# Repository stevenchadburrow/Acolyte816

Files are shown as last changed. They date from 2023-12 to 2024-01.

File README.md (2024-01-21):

# Acolyte816

An Acolyte Computer using the W65C816S.

It runs at 12.5 MHz and has 1 MB of RAM.  Video output of 64-colors at 320x240 or monochrome at 640x240.  PS/2 Keyboard and Mouse, 2x Genesis Controllers, and 1-Voice Square wave audio output.

This is a ROM-less design, having 512 bytes of bootloader code in the PIC16F886 "spoon feeding" the '816 on power-up or reset.  After that the PIC controls the MicroSD Card to access up to 2GB of memory.

The Simulator is powered by gianlucag's 6502 emulator library, with Agumander's W65C02 edits.  The LICENSE.txt pertains to the "mos6502-Edit816.h" and "mos6502-Edit816.cpp" files only.

BODGES REQUIRED:  The 74AHCT245 connected to the PIC needs two changes: One, Pin 1 is no longer R/W but instead connected to +5V. Two, Pin 19 is connected to RC5.  Also, the FTDI USB 6-pin connector has RTS and DTS lines cut and no longer connected to RC4 and RC5.

A picture of the board after bodges.
<kbd>
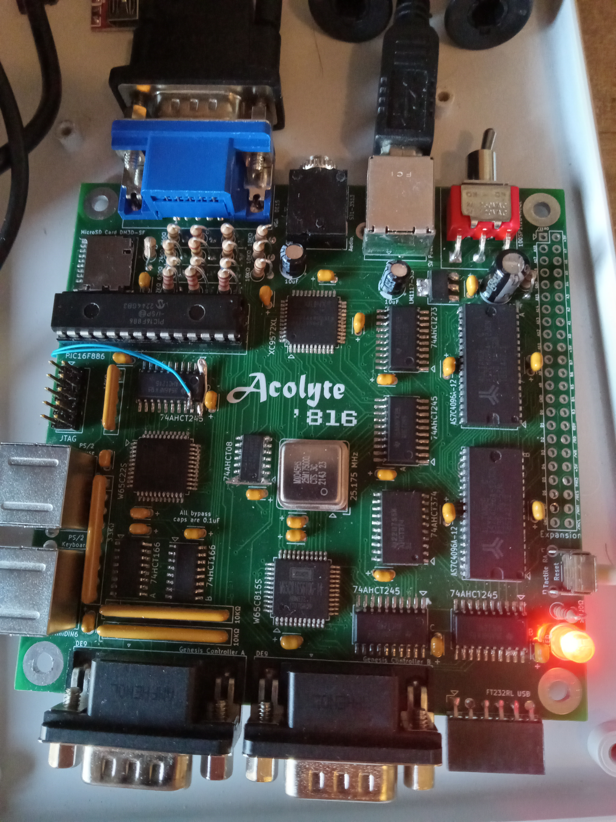
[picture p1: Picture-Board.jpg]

</kbd>

Splash showing 64-colors and text display together.
<kbd>
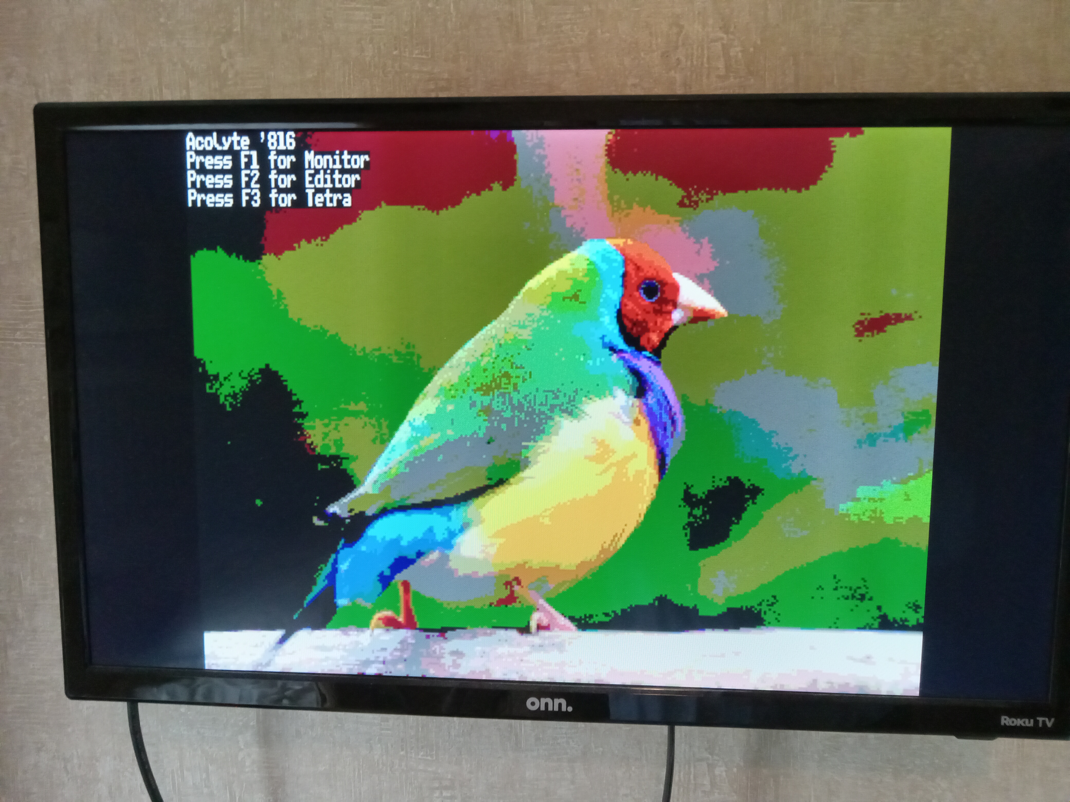
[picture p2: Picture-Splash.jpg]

</kbd>

Bootloader fallback monitor, when SDcard is not present.
<kbd>
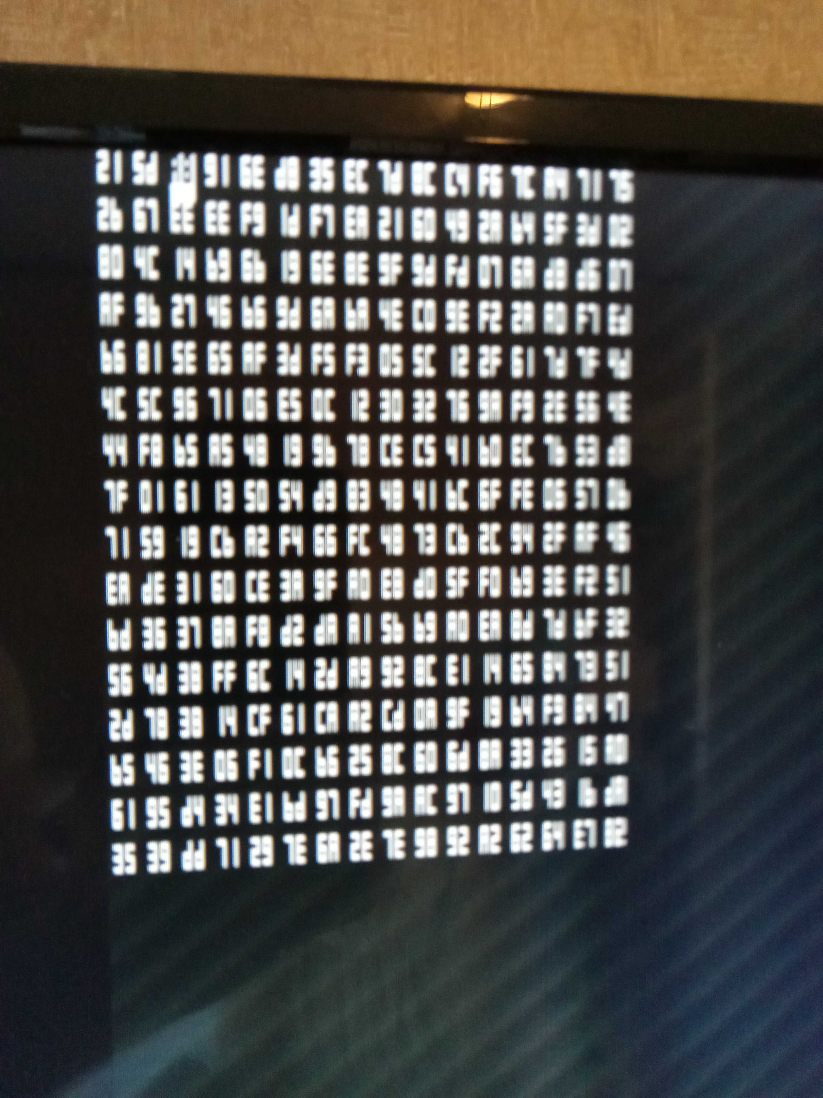
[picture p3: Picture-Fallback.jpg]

</kbd>

Basic system monitor for read/write/execute.
<kbd>
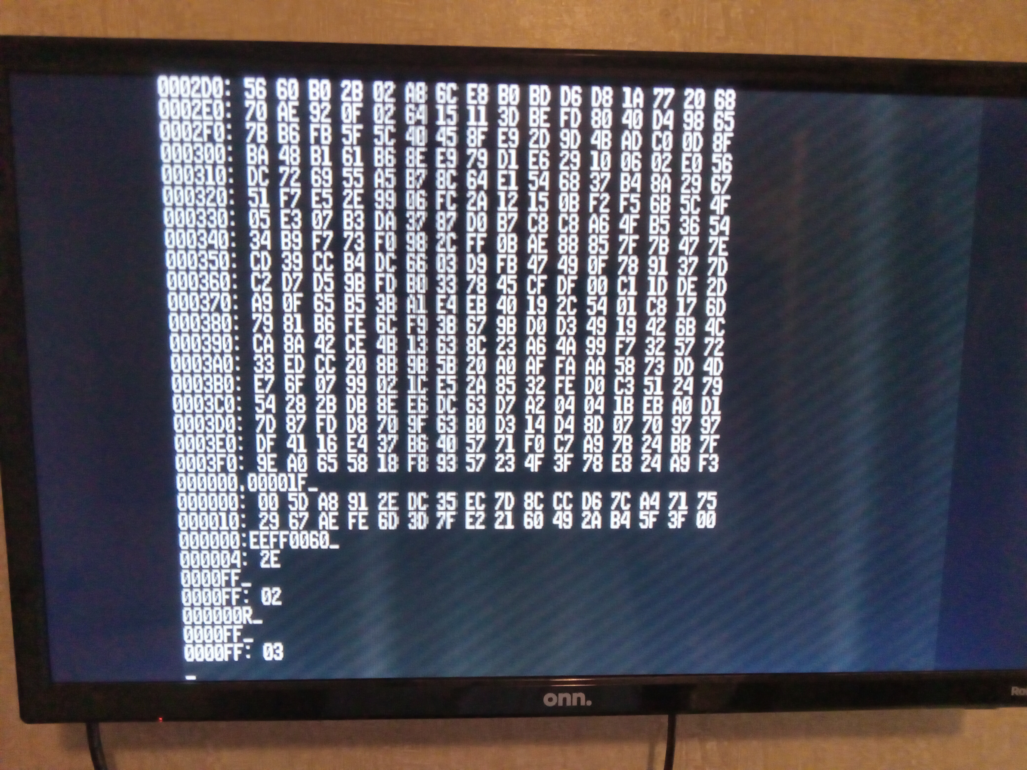
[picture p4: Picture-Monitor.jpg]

</kbd>

Text editor with vertical scrolling, will be used as IDE for a higher level language soon.
<kbd>
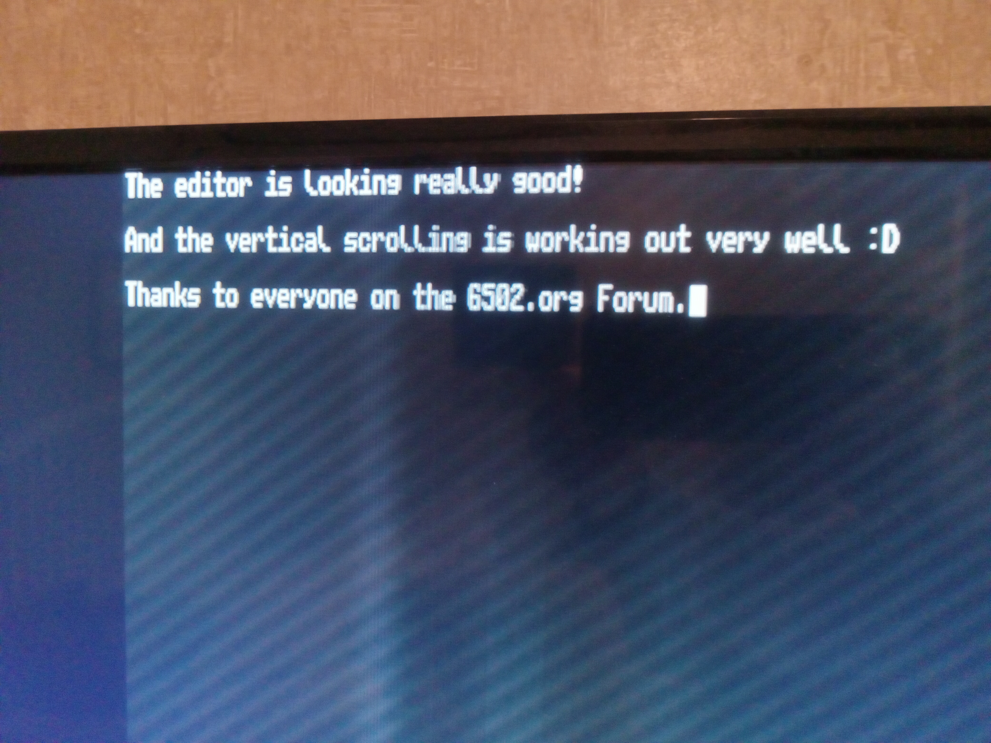
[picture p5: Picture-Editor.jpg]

</kbd>

First game for the system: Tetra!
<kbd>
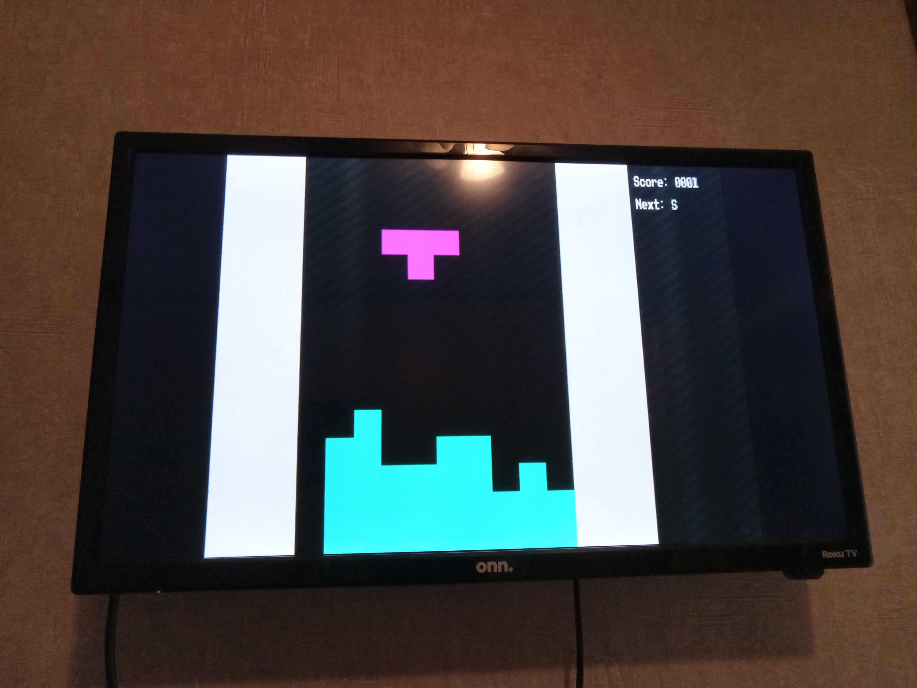
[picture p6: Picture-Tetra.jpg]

</kbd>

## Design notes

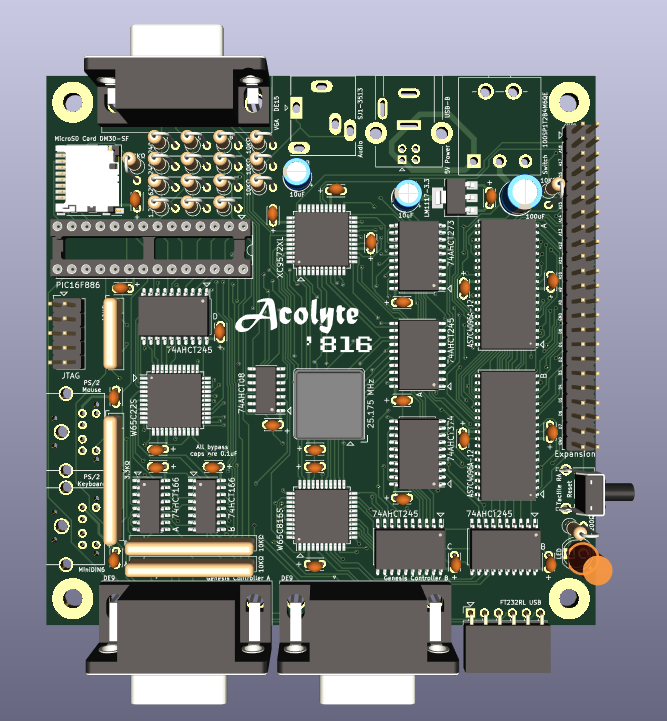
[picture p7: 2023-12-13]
Acolyte816-Routed.png

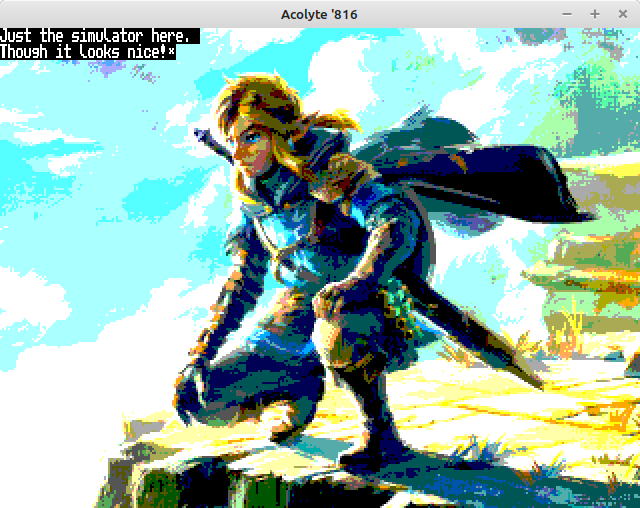
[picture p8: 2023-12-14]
Simulator-Demo.png

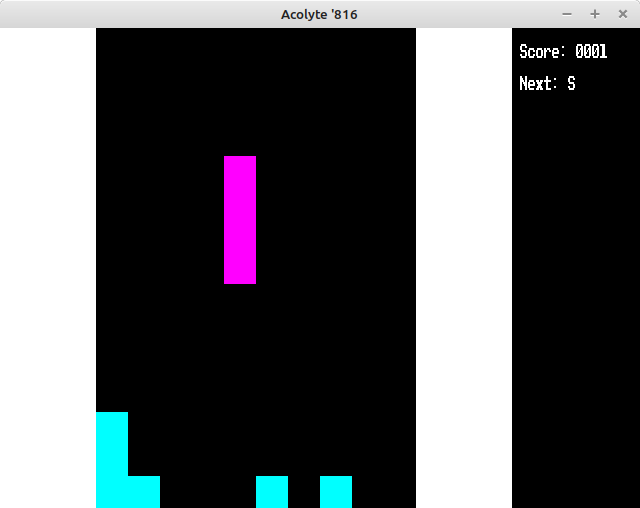
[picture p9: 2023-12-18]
Simulator-Tetra.png

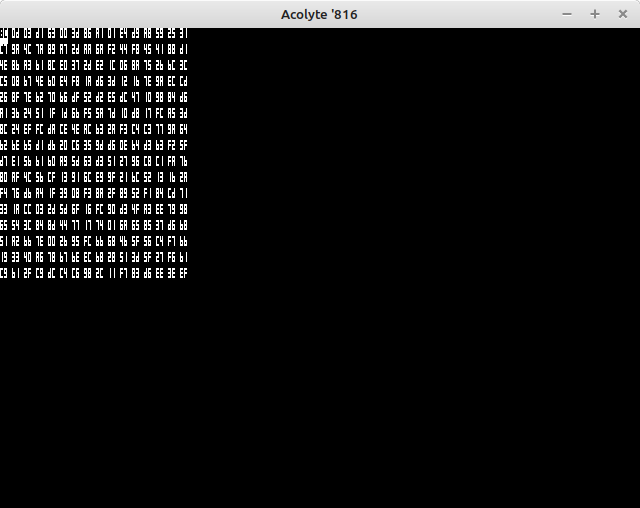
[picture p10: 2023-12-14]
Simulator-Bootloader.png

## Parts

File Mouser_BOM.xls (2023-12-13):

SHOPPING CART
This is not an invoice
13-Dec-23 14:43:57
 | Mouser # | Mfr. # | Manufacturer | Customer # | Description | RoHS | Lifecycle | Order Qty. | Price (USD) | Ext.: (USD)
1 | 913-AS7C4096A-12JCN | AS7C4096A-12JCN | Alliance Memory |  | SRAM SRAM, 4Mb, 512K x 8, 5V, 36pin SOJ, 12ns, Commercial Temp - Tube | RoHS Compliant |  | 2 | $5.77 | $11.54
2 | 955-W65C816S6TQG-14 | W65C816S6TQG-14 | Western Design Center (WDC) |  | Microprocessors - MPU 16-bit MPU 44 Pin QFP package | RoHS Compliant |  | 1 | $9.97 | $9.97
3 | 955-W65C22S6TQG-14 | W65C22S6TQG-14 | Western Design Center (WDC) |  | I/O Controller Interface IC Interface Adapter 44 Pin QFP package | RoHS Compliant |  | 1 | $9.66 | $9.66
4 | 579-PIC16F886-I/SP | PIC16F886-I/SP | Microchip |  | 8-bit Microcontrollers - MCU 14KB Flash 368 RAM 25 I/O | RoHS Compliant |  | 2 | $2.97 | $5.94
5 | 217-XC9572XL-7VQG44C | XC9572XL-7VQG44C | Xilinx |  | CPLD - Complex Programmable Logic Devices 3.3V 72-mc CPLD | RoHS Compliant |  | 1 | $13.50 | $13.50
6 | 595-SN74AHCT245PWR | SN74AHCT245PWR | Texas Instruments |  | Bus Transceivers Tri-State Octal Bus | RoHS Compliant |  | 4 | $0.46 | $1.84
7 | 595-SN74AHCT374PWR | SN74AHCT374PWR | Texas Instruments |  | Flip Flops Tri-State Octal | RoHS Compliant |  | 1 | $0.43 | $0.43
8 | 595-SN74AHCT273PWR | SN74AHCT273PWR | Texas Instruments |  | Flip Flops Octal w/ Clear | RoHS Compliant |  | 1 | $0.61 | $0.61
9 | 798-DM3D-SF | DM3D-SF | Hirose Electric |  | Memory Card Connectors MICRO SD CD CONN STD SMT PUSHPULL | RoHS Compliant |  | 1 | $1.82 | $1.82
10 | 649-61729-1011RLF | 61729-1011RLF | Amphenol |  | USB Connectors 4P R/A RECEPTACLE STYLE B | RoHS Compliant |  | 1 | $1.14 | $1.14
11 | 926-LM1117MP-3.3NOPB | LM1117MP-3.3/NOPB | Texas Instruments |  | LDO Voltage Regulators 800MA LDO LINEAR REG | RoHS Compliant |  | 1 | $1.61 | $1.61
12 | 667-ECE-A1VKS100I | ECE-A1VKS100I | Panasonic |  | Aluminum Electrolytic Capacitors - Radial Leaded 35VDC 10uF SU | RoHS Compliant |  | 2 | $0.26 | $0.52
13 | 667-ECA-1VHG101 | ECA-1VHG101 | Panasonic |  | Aluminum Electrolytic Capacitors - Radial Leaded 100uF 35V | RoHS Compliant |  | 1 | $0.32 | $0.32
14 | 941-C503CRCSCYAZAAA2 | C503C-RCS-CYAZAAA2 | Cree LED |  | Standard LEDs - Through Hole Red Round | RoHS Compliant |  | 2 | $0.21 | $0.42
15 | 523-7HDE15SD1CH4FVGA | L77HDE15SD1CH4FVGA | Amphenol |  | D-Sub High Density Connectors D SUB R/A |  |  | 1 | $1.73 | $1.73
16 | 523-G17C0910132EU | G17C0910132EU | Amphenol |  | D-Sub Standard Connectors D-SUB,PLUG,FP=8.08MM, 9-POS,R/A DIP,W/#4-40 IN |  |  | 2 | $1.40 | $2.80
17 | 771-HCT166D653 | 74HCT166D,653 | Nexperia |  | Counter Shift Registers 74HCT166D/SOT109/SO16 | RoHS Compliant |  | 2 | $0.64 | $1.28
18 | 490-SJ1-3513 | SJ1-3513 | CUI Devices |  | Phone Connectors Audio Jacks | RoHS Compliant |  | 1 | $1.80 | $1.80
19 | 612-100-A2461 | 100SP1T2B4M6QE | E-Switch |  | Toggle Switches SPDT ON-ON PC MNT | RoHS Compliant By Exemption |  | 1 | $3.72 | $3.72
20 | 774-MXO45HS-3C-25.1 | MXO45HS-3C-25M1750 | CTS |  | Standard Clock Oscillators 25.175MHz 50ppm 8Pin DIP/STD | RoHS Compliant |  | 1 | $3.89 | $3.89
21 | 571-1-2199298-9 | 1-2199298-9 | TE Connectivity |  | IC & Component Sockets 28P DIP SKT 300 CL LADDER | RoHS Compliant |  | 1 | $0.69 | $0.69
22 | 771-AHCT08D118 | 74AHCT08D,118 | Nexperia |  | Logic Gates 74AHCT08D/SOT108/SO14 | RoHS Compliant |  | 1 | $0.49 | $0.49
23 | 506-1-1977177-8 | 1-1977177-8 | TE Connectivity |  | Tactile Switches R/A TACT SWITCH 160 | RoHS Compliant |  | 1 | $0.51 | $0.51
24 | 200-SSQ10602TSRA | SSQ-106-02-T-S-RA | Samtec |  | Headers & Wire Housings Tiger Buy Socket Strip with Square Tails, 0.100" Pitch | RoHS Compliant |  | 1 | $1.14 | $1.14
25 | 652-4609X-AP1-103LF | 4609X-AP1-103LF | Bourns |  | Resistor Networks & Arrays THICK FILM 2% 10K CONFRML SIP | RoHS Compliant By Exemption |  | 2 | $0.58 | $1.16
26 | 652-4609X-1LF-3.3K | 4609X-101-332LF | Bourns |  | Resistor Networks & Arrays 9pins 3.3Kohms Bussed | RoHS Compliant By Exemption |  | 1 | $0.42 | $0.42
27 | 652-4605X-1LF-10K | 4605X-101-103LF | Bourns |  | Resistor Networks & Arrays 5pins 10Kohms Bussed | RoHS Compliant By Exemption |  | 1 | $0.39 | $0.39
28 | 603-CFR-25JR-5210K | CFR-25JR-52-10K | YAGEO |  | Carbon Film Resistors - Through Hole 10kOhms 250mW 350V 0 PPM/C to - 500 PPM/C 5% | RoHS Compliant |  | 10 | $0.037 | $0.37
29 | 603-CFR-25JR-521K2 | CFR-25JR-52-1K2 | YAGEO |  | Carbon Film Resistors - Through Hole 1.2K ohm 1/4W 5% | RoHS Compliant |  | 10 | $0.037 | $0.37
30 | 603-CFR-25JB-52-620R | CFR-25JB-52-620R | YAGEO |  | Carbon Film Resistors - Through Hole 1/4W 620 Ohm 5% | RoHS Compliant |  | 10 | $0.037 | $0.37
31 | 603-CFR-25JB-52-240R | CFR-25JB-52-240R | YAGEO |  | Carbon Film Resistors - Through Hole 1/4W 240 Ohm 5% | RoHS Compliant |  | 10 | $0.035 | $0.35
32 | 806-KMDGX-6S-BS | KMDGX-6S-BS | Kycon |  | Circular DIN Connectors 6P R/A FULL SHIELD GOLD PLANTED | RoHS Compliant |  | 2 | $1.73 | $3.46
33 | 649-67997-210HLF | 67997-210HLF | Amphenol |  | Headers & Wire Housings 10P DR VERT HDR | RoHS Compliant |  | 2 | $0.51 | $1.02
34 | 594-K104K15X7RF5UL2 | K104K15X7RF5UL2 | Vishay |  | Multilayer Ceramic Capacitors MLCC - Leaded K 50V 100NF +/- 10 % X7R AMMO E3 | RoHS Compliant By Exemption |  | 30 | $0.107 | $3.21
By submitting your order you agree to these terms and conditions. (https://www.mouser.com/saleterms) |  |  |  |  |  |  |  |  | Merchandise: | $88.49
Prices are reflected at the date and time shown. |  |  |  |  |  |  |  |  | Shipping Charge: | $9.99

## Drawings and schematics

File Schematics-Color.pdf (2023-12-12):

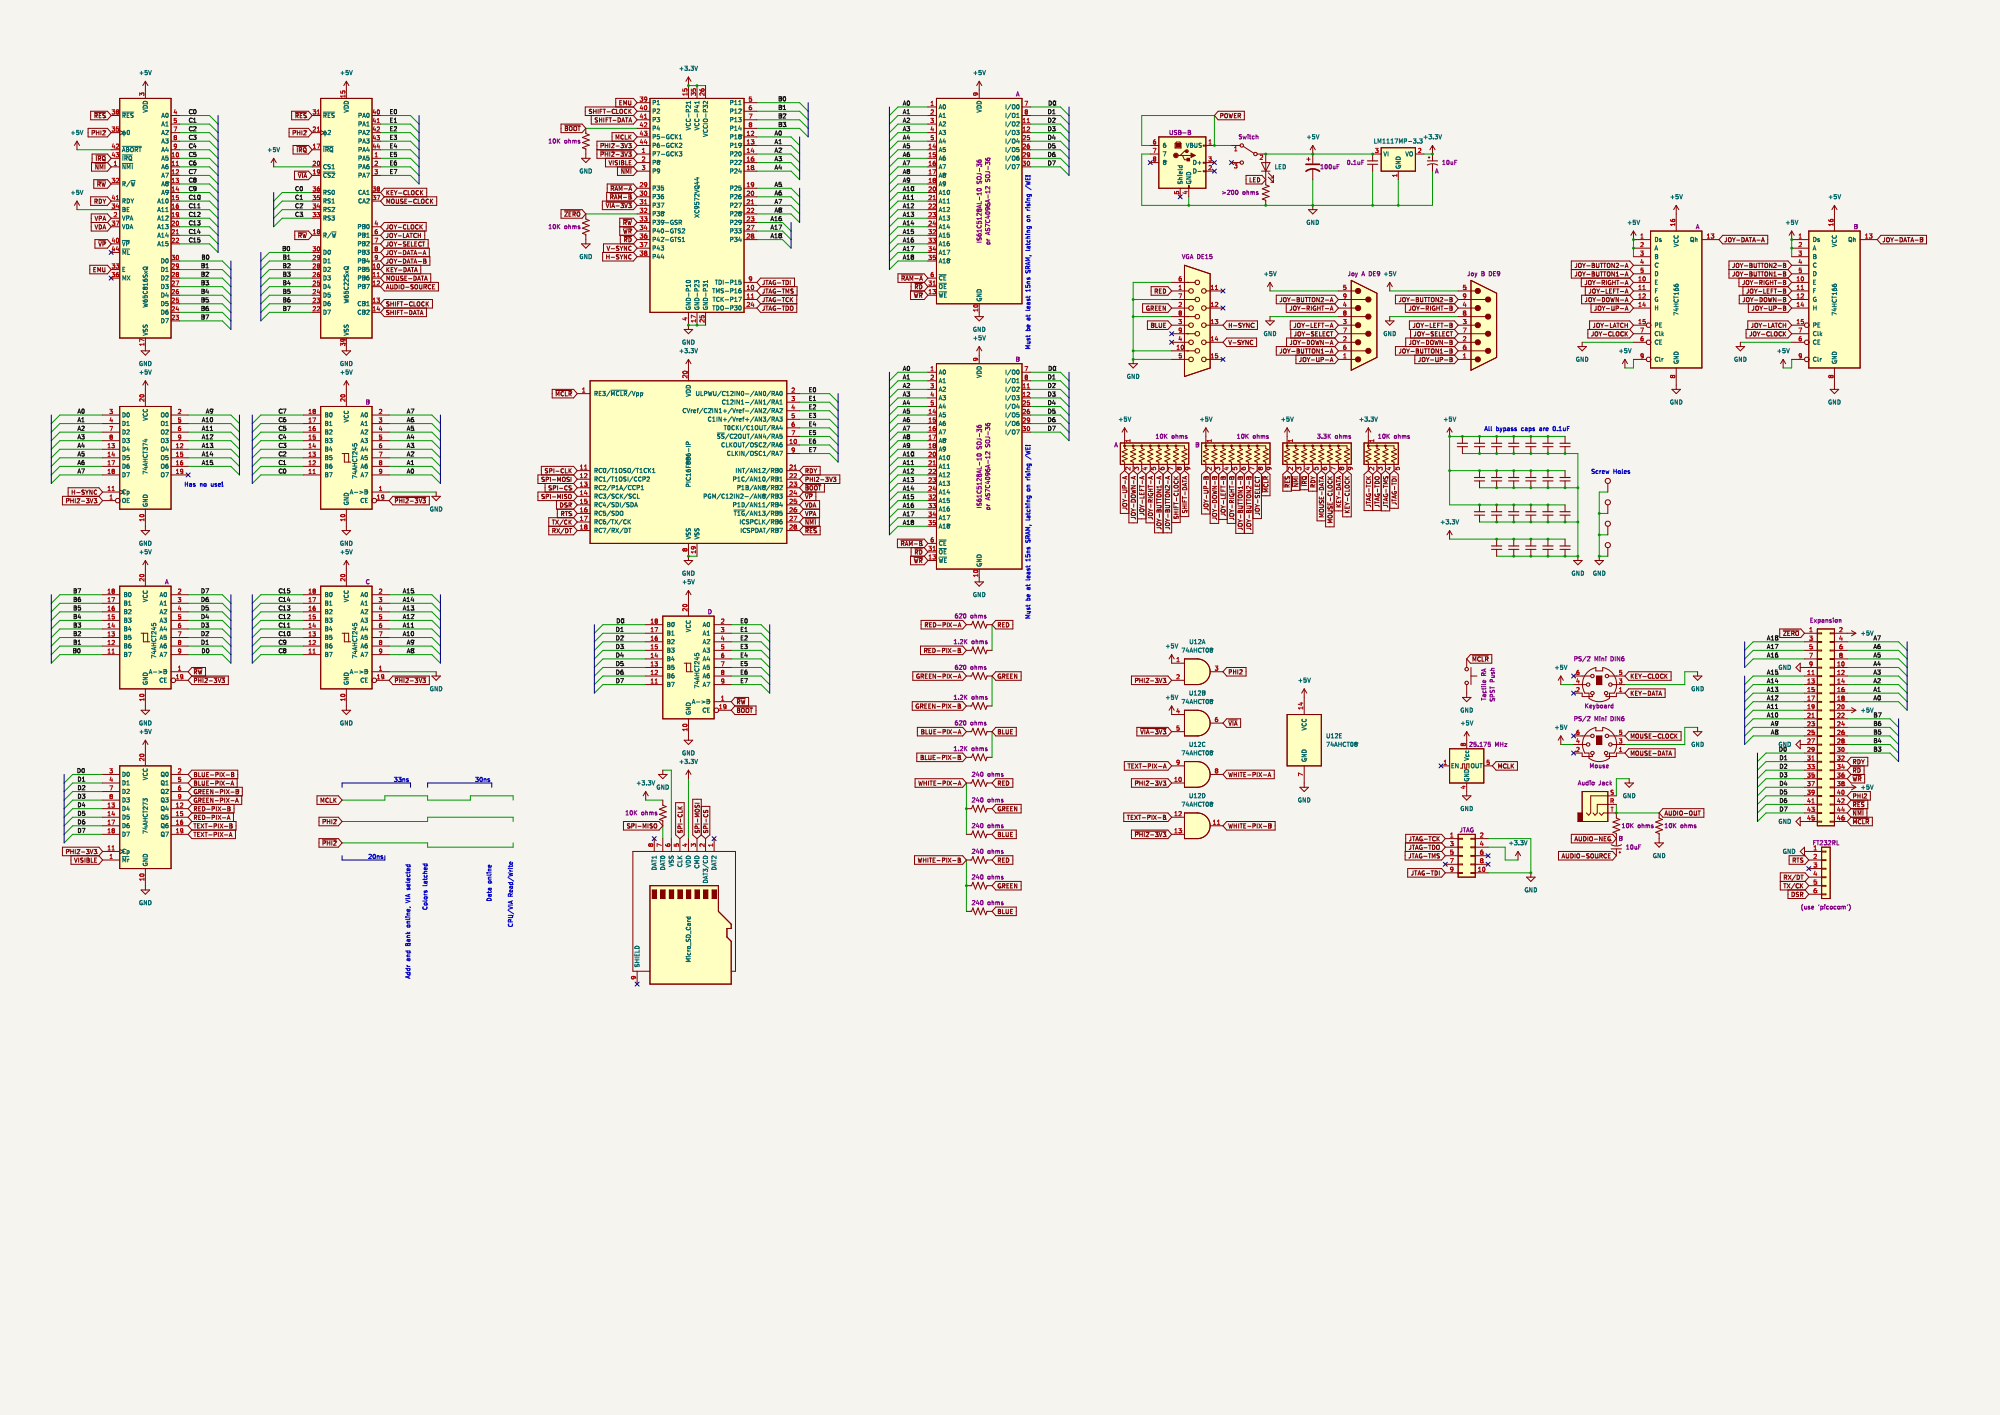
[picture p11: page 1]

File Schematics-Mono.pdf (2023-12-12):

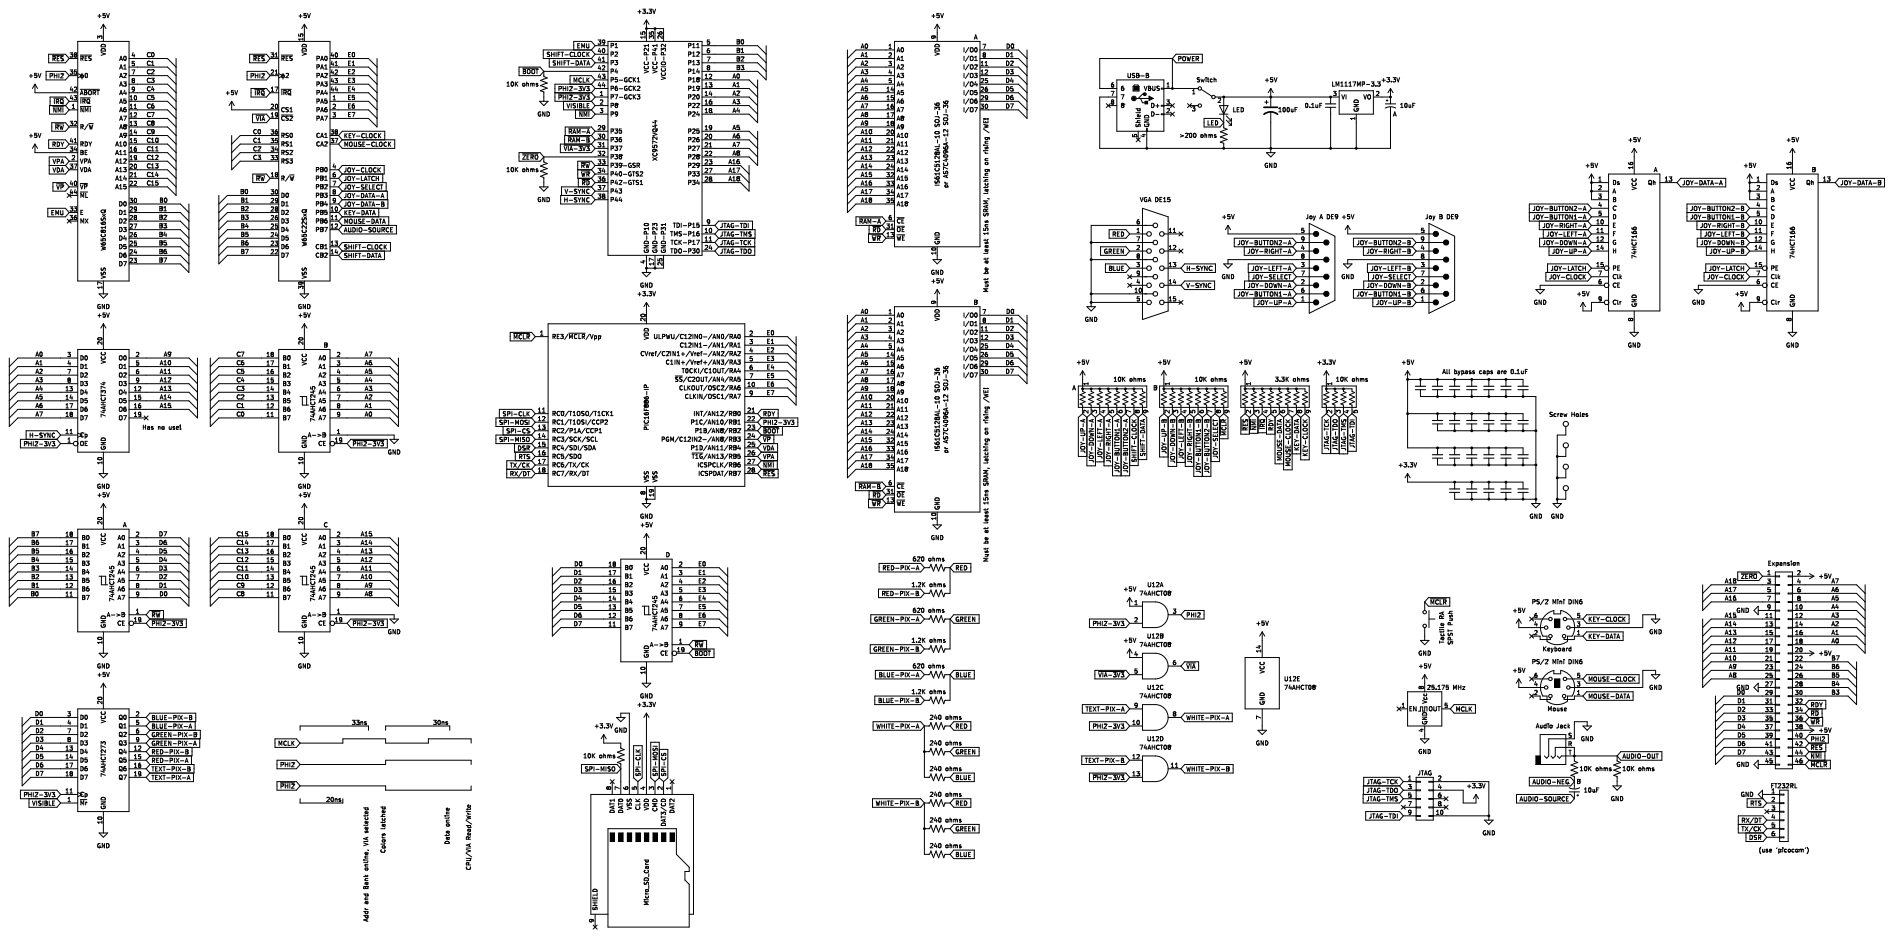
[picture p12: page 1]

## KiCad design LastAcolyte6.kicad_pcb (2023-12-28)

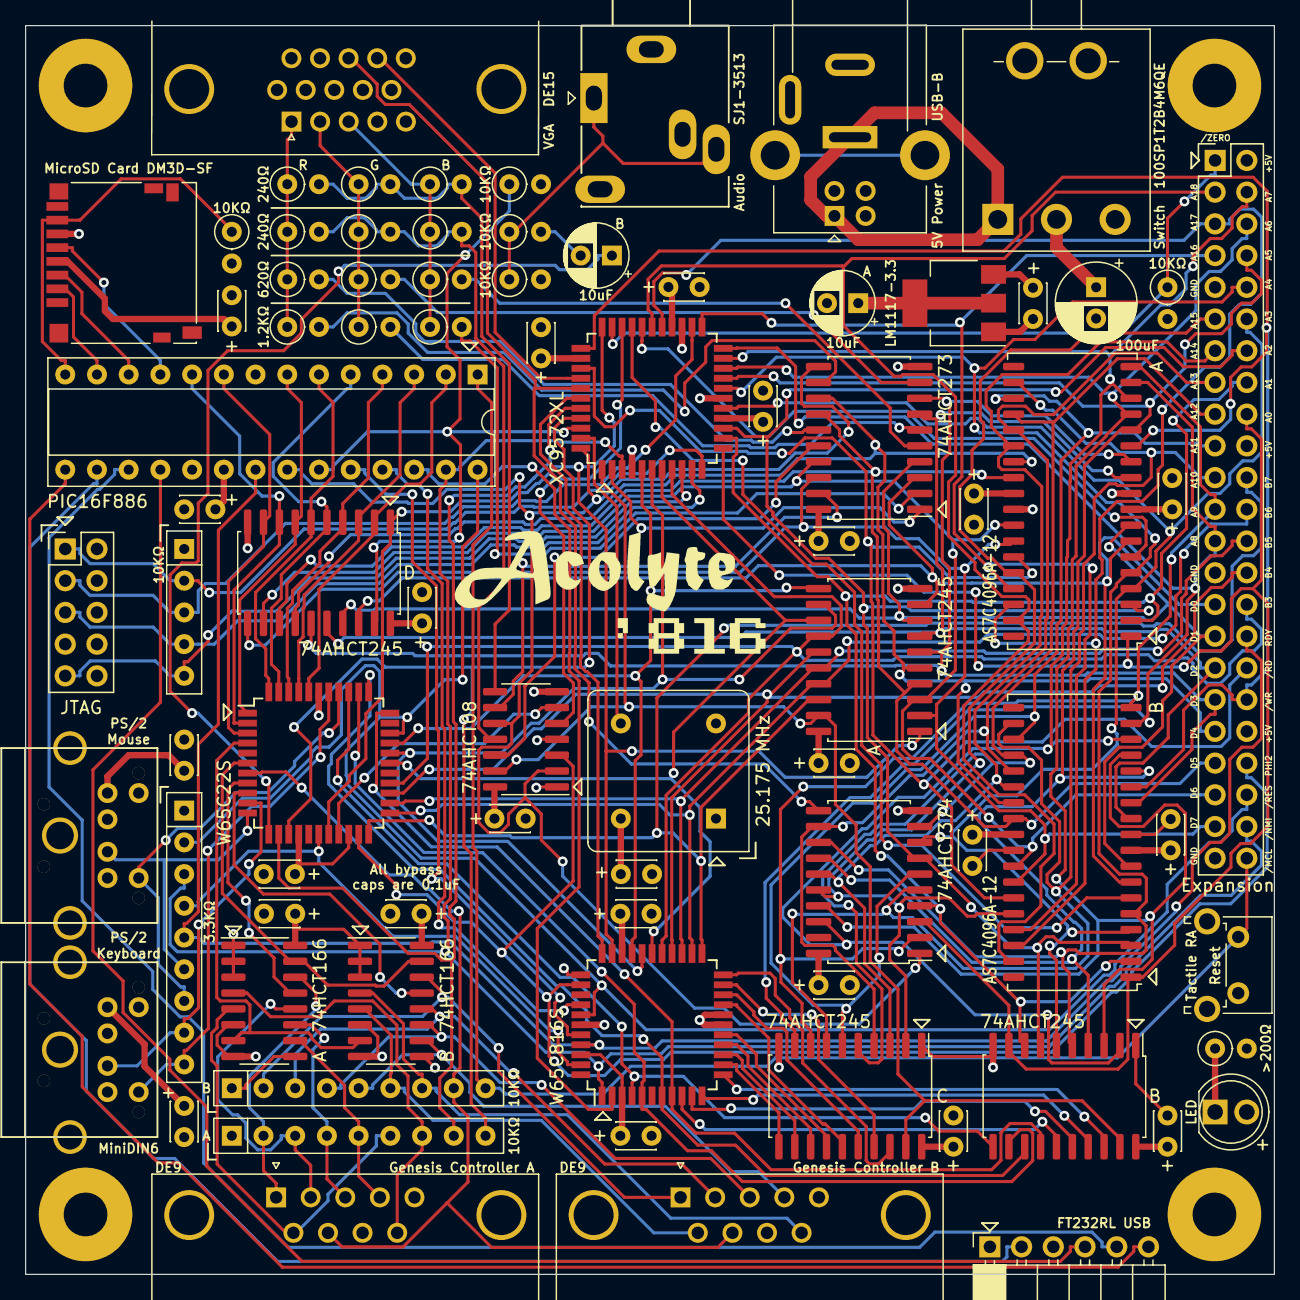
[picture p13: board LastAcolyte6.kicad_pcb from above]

Board: 4 copper layers, 100.0 x 100.0 mm, 88 parts (1 on the bottom side), 140 nets.

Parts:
C1: C_Polarized_US; CP_Radial_D6.3mm_P2.50mm
C2, C4, C5, C6, C7, C8, C9, C10, C11, C12, C13, C14, C15, C16, C17, C18, C19, C20, C21, C23, C24, C25, C26, C27, C28: C_Small; C_Disc_D3.0mm_W2.0mm_P2.50mm
C3, C22: C_Polarized_Small_US; CP_Radial_D5.0mm_P2.50mm
D1: LED; CustomLED
G102: LOGO; Mystery
G1000: LOGO; AcolyteTitle
G1001: LOGO; Acolyte816
J1: Conn_02x23_Odd_Even; PinHeader_2x23_P2.54mm_Vertical
J2, J4: DE9_Plug; DSUB-9_Male_Horizontal_P2.77x2.84mm_EdgePinOffset7.70mm_Hou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
J3: Conn_02x05_Odd_Even; PinHeader_2x05_P2.54mm_Vertical
J5: DE15_Receptacle_HighDensity; DSUB-15-HD_Female_Horizontal_P2.29x2.54mm_VGA
J6: AudioJack3; BIGJack_3.5mm_Ledino_KB3SPRS_Horizontal
J7, J8: Mini-DIN-6; PS2_Din6
J9: Micro_SD_Card; microSD_HC_Hirose_DM3D-SF
J10: DualPower_USB_B; DualPowerSupply
J11: Conn_01x06; PinSocket_1x06_P2.54mm_Horizontal
R3, R4, R5, R7, R8, R9, R10, R11, R12, R13, R14, R15, R16, R18, R19, R20, R21, R22: R_US; R_Axial_DIN0207_L6.3mm_D2.5mm_P2.54mm_Vertical
RN1, RN2, RN3: R_Network08_US; R_Array_SIP9
RN4: R_Network04_US; R_Array_SIP5
SW1: SW_Push; SW_Tactile_SPST_Angled_PTS645Vx83-2LFS
SW2: SW_SPDT; SPDT-100SP1T2B4M6QE
TP1, TP2, TP3, TP4: TestPoint; ScrewHole-4-40
U1: XC9572VQ44; TQFP-44_10x10mm_P0.8mm
U2, U7: IS61C5128AL-10KLI; SOJ-36_10.16x23.49mm_P1.27mm
U3: LM1117MP-3.3; SOT-223-3_TabPin2
U4: W65C816SxQ; TQFP-44_10x10mm_P0.8mm
U5: W65C22SxQ; TQFP-44_10x10mm_P0.8mm
U6: 74AHCT273; SOIC-20-Adj_7.5x12.8mm_P1.27mm
U8, U9: 74HCT166; SOIC-16_3.9x9.9mm_P1.27mm
U10, U11, U15, U16: 74AHCT245; SOIC-20-Adj_7.5x12.8mm_P1.27mm
U12: 74AHCT08; SOIC-14_3.9x8.7mm_P1.27mm
U19: 74AHCT374; SOIC-20-Adj_7.5x12.8mm_P1.27mm
U21: PIC16F886-IP; DIP-28_W7.62mm_Socket
X1: CXO_DIP8; Oscillator_DIP-8

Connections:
+3.3V: C3.1, C5.2, C9.2, C13.2, C17.2, C21.2, J3.4, J9.4 (VDD), R3.2, RN4.1 (common), U1.15 (VCC-P21), U1.26 (VCCIO-P32), U1.35 (VCC-P41), U3.2 (VO), U21.20 (VDD)
+5V: C1.1, C2.2, C4.2, C6.2, C7.2, C8.2, C10.2, C11.2, C12.2, C14.2, C15.2, C16.2, C18.2, C19.2, C20.2, C23.2, C24.2, C25.2, C26.2, C27.2, C28.2, D1.2 (A), J1.2, J1.20, J1.38, J2.5, J4.5, J7.4, J8.4, RN1.1 (common), RN2.1 (common), RN3.1 (common), SW2.2 (B), U2.9 (VDD), U2.27 (VDD), U3.3 (VI), U4.3 (VDD), U4.31 (VDD), U4.34 (BE), U4.42 (~ABORT), U5.15 (VDD), U5.20 (CS1), U6.20 (VCC), U7.9 (VDD), U7.27 (VDD), U8.1 (Ds), U8.2 (A), U8.3 (B), U8.9 (Clr), U8.16 (VCC), U9.1 (Ds), U9.2 (A), U9.3 (B), U9.9 (Clr), U9.16 (VCC), U10.20 (VCC), U11.20 (VCC), U12.1, U12.4, U12.14 (VCC), U15.20 (VCC), U16.20 (VCC), U19.20 (VCC), X1.8 (Vcc)
/A0: J1.18, U1.12 (P18), U2.1 (A0), U7.1 (A0), U15.9 (A7), U19.3 (D0)
/A1: J1.16, U1.13 (P19), U2.2 (A1), U7.2 (A1), U15.8 (A6), U19.4 (D1)
/A2: J1.14, U1.14 (P20), U2.3 (A2), U7.3 (A2), U15.7 (A5), U19.7 (D2)
/A3: J1.12, U1.16 (P22), U2.4 (A3), U7.4 (A3), U15.6 (A4), U19.8 (D3)
/A4: J1.10, U1.18 (P24), U2.5 (A4), U7.5 (A4), U15.5 (A3), U19.13 (D4)
/A5: J1.8, U1.19 (P25), U2.14 (A5), U7.14 (A5), U15.4 (A2), U19.14 (D5)
/A6: J1.6, U1.20 (P26), U2.15 (A6), U7.15 (A6), U15.3 (A1), U19.17 (D6)
/A7: J1.4, U1.21 (P27), U2.16 (A7), U7.16 (A7), U15.2 (A0), U19.18 (D7)
/A8: J1.25, U1.22 (P28), U2.17 (A8), U7.17 (A8), U16.9 (A7)
/A9: J1.23, U2.18 (A9), U7.18 (A9), U16.8 (A6), U19.2 (O0)
/A10: J1.21, U2.20 (A10), U7.20 (A10), U16.7 (A5), U19.5 (O1)
/A11: J1.19, U2.21 (A11), U7.21 (A11), U16.6 (A4), U19.6 (O2)
/A12: J1.17, U2.22 (A12), U7.22 (A12), U16.5 (A3), U19.9 (O3)
/A13: J1.15, U2.23 (A13), U7.23 (A13), U16.4 (A2), U19.12 (O4)
/A14: J1.13, U2.24 (A14), U7.24 (A14), U16.3 (A1), U19.15 (O5)
/A15: J1.11, U2.32 (A15), U7.32 (A15), U16.2 (A0), U19.16 (O6)
/A16: J1.7, U1.23 (P29), U2.33 (A16), U7.33 (A16)
/A17: J1.5, U1.27 (P33), U2.34 (A17), U7.34 (A17)
/A18: J1.3, U1.28 (P34), U2.35 (A18), U7.35 (A18)
/B0: U1.5 (P11), U4.30 (D0), U5.30 (D0), U10.11 (B7)
/B1: U1.6 (P12), U4.29 (D1), U5.29 (D1), U10.12 (B6)
/B2: U1.7 (P13), U4.28 (D2), U5.28 (D2), U10.13 (B5)
/B3: J1.30, U1.8 (P14), U4.27 (D3), U5.26 (D3), U10.14 (B4)
/B4: J1.28, U4.26 (D4), U5.25 (D4), U10.15 (B3)
/B5: J1.26, U4.25 (D5), U5.24 (D5), U10.16 (B2)
/B6: J1.24, U4.24 (D6), U5.23 (D6), U10.17 (B1)
/B7: J1.22, U4.23 (D7), U5.22 (D7), U10.18 (B0)
/C0: U4.4 (A0), U5.36 (RS0), U15.11 (B7)
/C1: U4.5 (A1), U5.35 (RS1), U15.12 (B6)
/C2: U4.7 (A2), U5.34 (RS2), U15.13 (B5)
/C3: U4.8 (A3), U5.33 (RS3), U15.14 (B4)
/C4: U4.9 (A4), U15.15 (B3)
/C5: U4.10 (A5), U15.16 (B2)
/C6: U4.11 (A6), U15.17 (B1)
/C7: U4.12 (A7), U15.18 (B0)
/C8: U4.13 (A8), U16.11 (B7)
/C9: U4.14 (A9), U16.12 (B6)
/C10: U4.15 (A10), U16.13 (B5)
/C11: U4.16 (A11), U16.14 (B4)
/C12: U4.19 (A12), U16.15 (B3)
/C13: U4.20 (A13), U16.16 (B2)
/C14: U4.21 (A14), U16.17 (B1)
/C15: U4.22 (A15), U16.18 (B0)
/D0: J1.29, U2.7 (I/O0), U6.3 (D0), U7.7 (I/O0), U10.9 (A7), U11.18 (B0)
/D1: J1.31, U2.8 (I/O1), U6.4 (D1), U7.8 (I/O1), U10.8 (A6), U11.17 (B1)
/D2: J1.33, U2.11 (I/O2), U6.7 (D2), U7.11 (I/O2), U10.7 (A5), U11.16 (B2)
/D3: J1.35, U2.12 (I/O3), U6.8 (D3), U7.12 (I/O3), U10.6 (A4), U11.15 (B3)
/D4: J1.37, U2.25 (I/O4), U6.13 (D4), U7.25 (I/O4), U10.5 (A3), U11.14 (B4)
/D5: J1.39, U2.26 (I/O5), U6.14 (D5), U7.26 (I/O5), U10.4 (A2), U11.13 (B5)
/D6: J1.41, U2.29 (I/O6), U6.17 (D6), U7.29 (I/O6), U10.3 (A1), U11.12 (B6)
/D7: J1.43, U2.30 (I/O7), U6.18 (D7), U7.30 (I/O7), U10.2 (A0), U11.11 (B7)
/E0: U5.40 (PA0), U11.2 (A0), U21.2 (ULPWU/C12IN0-/AN0/RA0)
/E1: U5.41 (PA1), U11.3 (A1), U21.3 (C12IN1-/AN1/RA1)
/E2: U5.42 (PA2), U11.4 (A2), U21.4 (CVref/C2IN1+/Vref-/AN2/RA2)
/E3: U5.43 (PA3), U11.5 (A3), U21.5 (C1IN+/Vref+/AN3/RA3)
/E4: U5.44 (PA4), U11.6 (A4), U21.6 (T0CKI/C1OUT/RA4)
/E5: U5.1 (PA5), U11.7 (A5), U21.7 (~SS/C2OUT/AN4/RA5)
/E6: U5.2 (PA6), U11.8 (A6), U21.10 (CLKOUT/OSC2/RA6)
/E7: U5.3 (PA7), U11.9 (A7), U21.9 (CLKIN/OSC1/RA7)
AUDIO-NEG: C22.2, R14.2
AUDIO-OUT: J6.R, J6.T, R14.1, R16.1
AUDIO-SOURCE: C22.1, U5.12 (PB7)
BLUE: J5.3, R12.1, R13.1, R19.1, R22.1
BLUE-PIX-A: R12.2, U6.5 (Q1)
BLUE-PIX-B: R13.2, U6.2 (Q0)
DSR: J11.6, U21.15 (RC4/SDI/SDA)
EMU: U1.39 (P1), U4.33 (E)
GND: C1.2, C2.1, C3.2, C4.1, C5.1, C6.1, C7.1, C8.1, C9.1, C10.1, C11.1, C12.1, C13.1, C14.1, C15.1, C16.1, C17.1, C18.1, C19.1, C20.1, C21.1, C23.1, C24.1, C25.1, C26.1, C27.1, C28.1, J1.9, J1.27, J1.45, J2.8, J3.2, J3.10, J4.8, J5.5, J5.6, J5.7, J5.8, J5.10, J6.S, J7.3, J8.3, J9.6 (VSS), J10.4 (GND), J10.7, J11.1, R4.2, R5.2, R7.2, R16.2, SW1.2, TP1.1, TP2.1, TP3.1, TP4.1, U1.4 (GND-P10), U1.17 (GND-P23), U1.25 (GND-P31), U2.10 (GND), U2.28 (GND), U3.1 (GND), U4.17 (VSS), U4.18 (VSS), U4.39 (VSS), U5.39 (VSS), U6.10 (GND), U7.10 (GND), U7.28 (GND), U8.6 (CE), U8.8 (GND), U9.6 (CE), U9.8 (GND), U10.10 (GND), U11.10 (GND), U12.7 (GND), U15.1 (A->B), U15.10 (GND), U16.1 (A->B), U16.10 (GND), U19.10 (GND), U21.8 (VSS), U21.19 (VSS), X1.4 (GND)
GREEN: J5.2, R10.1, R11.1, R18.1, R21.1
GREEN-PIX-A: R10.2, U6.9 (Q3)
GREEN-PIX-B: R11.2, U6.6 (Q2)
H-SYNC: J5.13, U1.38 (P44), U19.11 (Cp)
JOY-BUTTON1-A: J2.6, RN1.6 (R5), U8.5 (D)
JOY-BUTTON1-B: J4.6, RN2.6 (R5), U9.5 (D)
JOY-BUTTON2-A: J2.9, RN1.7 (R6), U8.4 (C)
JOY-BUTTON2-B: J4.9, RN2.7 (R6), U9.4 (C)
JOY-CLOCK: U5.4 (PB0), U8.7 (Clk), U9.7 (Clk)
JOY-DATA-A: U5.8 (PB3), U8.13 (Qh)
JOY-DATA-B: U5.9 (PB4), U9.13 (Qh)
JOY-DOWN-A: J2.2, RN1.3 (R2), U8.12 (G)
JOY-DOWN-B: J4.2, RN2.3 (R2), U9.12 (G)
JOY-LATCH: U5.6 (PB1), U8.15 (PE), U9.15 (PE)
JOY-LEFT-A: J2.3, RN1.4 (R3), U8.11 (F)
JOY-LEFT-B: J4.3, RN2.4 (R3), U9.11 (F)
JOY-RIGHT-A: J2.4, RN1.5 (R4), U8.10 (E)
JOY-RIGHT-B: J4.4, RN2.5 (R4), U9.10 (E)
JOY-SELECT: J2.7, J4.7, RN2.8 (R7), U5.7 (PB2)
JOY-UP-A: J2.1, RN1.2 (R1), U8.14 (H)
JOY-UP-B: J4.1, RN2.2 (R1), U9.14 (H)
JTAG-TCK: J3.1, RN4.2 (R1), U1.11 (TCK-P17)
JTAG-TDI: J3.9, RN4.5 (R4), U1.9 (TDI-P15)
JTAG-TDO: J3.3, RN4.3 (R2), U1.24 (TDO-P30)
JTAG-TMS: J3.5, RN4.4 (R3), U1.10 (TMS-P16)
KEY-CLOCK: J7.5, RN3.9 (R8), U5.38 (CA1)
KEY-DATA: J7.1, RN3.8 (R7), U5.10 (PB5)
LED: D1.1 (K), R7.1
MCLK: U1.43 (P5-GCK1), X1.5 (OUT)
MOUSE-CLOCK: J8.5, RN3.7 (R6), U5.37 (CA2)
MOUSE-DATA: J8.1, RN3.6 (R5), U5.11 (PB6)
PHI2: J1.40, U4.35 (ϕ0), U5.21 (ϕ2), U12.3
PHI2-3V3: U1.44 (P6-GCK2), U6.11 (Cp), U12.2, U12.10, U19.1 (OE), U21.22 (P1C/AN10/RB1)
POWER: J10.1 (VBUS), J10.6, SW2.1 (A)
RDY: J1.32, RN3.5 (R4), U4.41 (RDY), U21.21 (INT/AN12/RB0)
RED: J5.1, R8.1, R9.1, R15.1, R20.1
RED-PIX-A: R8.2, U6.15 (Q5)
RED-PIX-B: R9.2, U6.12 (Q4)
RTS: J11.2, U21.16 (RC5/SDO)
RX/DT: J11.4, U21.18 (RC7/RX/DT)
SHIFT-CLOCK: RN1.8 (R7), U1.40 (P2), U5.13 (CB1)
SHIFT-DATA: RN1.9 (R8), U1.41 (P3), U5.14 (CB2)
SPI-CLK: J9.5 (CLK), U21.11 (RC0/T1OSO/T1CK1)
SPI-CS: J9.2 (DAT3/CD), U21.13 (RC2/P1A/CCP1)
SPI-MISO: J9.7 (DAT0), R3.1, U21.14 (RC3/SCK/SCL)
SPI-MOSI: J9.3 (CMD), U21.12 (RC1/T1OSI/CCP2)
TEXT-PIX-A: U6.19 (Q7), U12.9
TEXT-PIX-B: U6.16 (Q6), U12.12
TX/CK: J11.5, U21.17 (RC6/TX/CK)
V-SYNC: J5.14, U1.37 (P43)
VDA: U4.37 (VDA), U21.25 (P1D/AN11/RB4)
VISIBLE: U1.2 (P8), U6.1 (~Mr)
VPA: U4.2 (VPA), U21.26 (~T1G/AN13/RB5)
WHITE-PIX-A: R15.2, R18.2, R19.2, U12.8
WHITE-PIX-B: R20.2, R21.2, R22.2, U12.11
~BOOT: R5.1, U1.42 (P4), U11.19 (CE), U21.23 (P1B/AN8/RB2)
~IRQ: RN3.4 (R3), U4.43 (~IRQ), U5.17 (~IRQ)
~MCLR: J1.46, RN2.9 (R8), SW1.1, U21.1 (RE3/~MCLR/Vpp)
~NMI: J1.44, RN3.3 (R2), U1.3 (P9), U4.1 (~NMI), U21.27 (ICSPCLK/RB6)
~PHI2-3V3: U1.1 (P7-GCK3), U10.19 (CE), U12.13, U15.19 (CE), U16.19 (CE)
~RAM-A: U1.29 (P35), U7.6 (~CE)
~RAM-B: U1.30 (P36), U2.6 (~CE)
~RD: J1.34, U1.36 (P42-GTS1), U2.31 (~OE), U7.31 (~OE)
~RES: J1.42, RN3.2 (R1), U4.38 (~RES), U5.31 (~RES), U21.28 (ICSPDAT/RB7)
~RW: U1.33 (P39-GSR), U4.32 (R/~W), U5.18 (R/~W), U10.1 (A->B), U11.1 (A->B)
~VIA-3V3: U1.31 (P37), U12.5
~VIA: U5.19 (~CS2), U12.6
~VP: U4.40 (~VP), U21.24 (PGM/C12IN2-/AN8/RB3)
~WR: J1.36, U1.34 (P40-GTS2), U2.13 (~WE), U7.13 (~WE)
~ZERO: J1.1, R4.1, U1.32 (P38)

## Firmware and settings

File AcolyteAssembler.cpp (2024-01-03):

// AcolyteAssembler.cpp

// Acolyte Assembler for the W65C816S

// g++ -o AcolyteAssembler.o AcolyteAssembler.cpp


#include <stdio.h>
#include <stdlib.h>
#include <string.h>
#include <math.h>

const int number_of_passes = 16; // 3 just isn't enough!

unsigned long current_line = 0;
unsigned long current_location = 0;

const unsigned long equal_max = 10000;
char equal_name[equal_max][256];
unsigned long equal_location[equal_max];
unsigned long equal_total = 0;
unsigned long equal_count = 0;

const unsigned long label_max = 10000;
char label_name[label_max][256];
unsigned long label_location[label_max];
unsigned long label_total = 0;
unsigned long label_count = 0;

const unsigned long star_max = 10000;
unsigned long star_location[star_max];
unsigned long star_total = 0;
unsigned long star_count = 0;

unsigned char binary_code[16777216]; // 16 MB possible code

const char *instruction_list[1024] = {

	"BRK","s","7","2",
	"ORA","(d,x)","6","2",
	"COP","s","7","2",
	"ORA","d,s","4","2",
	"TSB","d","5","2",
	"ORA","d","3","2",
	"ASL","d","5","2",
	"ORA","[d]","6","2",
	"PHP","s","3","1",
	"ORA","#","2","2",
	"ASL","A","2","1",
	"PHD","s","4","1",
	"TSB","a","6","3",
	"ORA","a","4","3",
	"ASL","a","6","3",
	"ORA","al","5","4",

	"BPL","r","2","2",
	"ORA","(d),y","5","2",
	"ORA","(d)","5","2",
	"ORA","(d,s),y","7","2",
	"TRB","d","5","2",
	"ORA","d,x","4","2",
	"ASL","d,x","6","2",
	"ORA","[d],y","6","2",
	"CLC","i","4","1",
	"ORA","a,y","4","3",
	"INC","A","2","1",
	"TCS","i","2","1",
	"TRB","a","6","3",
	"ORA","a,x","4","3",
	"ASL","a,x","7","3",
	"ORA","al,x","5","4",

	"JSR","a","6","3",
	"AND","(d,x)","6","2",
	"JSL","al","8","4",
	"AND","d,s","4","2",
	"BIT","d","3","2",
	"AND","d","3","2",
	"ROL","d","5","2",
	"AND","[d]","6","2",
	"PLP","s","4","1",
	"AND","#","2","2",
	"ROL","A","2","1",
	"PLD","s","5","1",
	"BIT","a","4","3",
	"AND","a","4","3",
	"ROL","a","6","3",
	"AND","al","5","4",

	"BMI","r","2","2",
	"AND","(d),y","5","2",
	"AND","(d)","5","2",
	"AND","(d,s),y","7","2",
	"BIT","d,x","4","2",
	"AND","d,x","4","2",
	"ROL","d,x","6","2",
	"AND","[d],y","6","2",
	"SEC","i","2","1",
	"AND","a,y","4","3",
	"DEC","A","2","1",
	"TSC","i","2","1",
	"BIT","a,x","4","3",
	"AND","a,x","4","3",
	"ROL","a,x","7","3",
	"AND","al,x","5","4",

	"RTI","s","7","1",
	"EOR","(d,x)","6","2",
	"WDM","i","2","2",
	"EOR","d,s","4","2",
	"MVP","xyc","7","3",
	"EOR","d","3","2",
	"LSR","d","5","2",
	"EOR","[d]","6","2",
	"PHA","s","3","1",
	"EOR","#","2","2",
	"LSR","A","2","1",
	"PHK","s","3","1",
	"JMP","a","3","3",
	"EOR","a","4","3",
	"LSR","a","6","3",
	"EOR","al","5","4",

	"BVC","r","2","2",
	"EOR","(d),y","5","2",
	"EOR","(d)","5","2",
	"EOR","(d,s),y","7","2",
	"MVN","xyc","7","3",
	"EOR","d,x","4","2",
	"LSR","d,x","6","2",
	"EOR","[d],y","6","2",
	"CLI","i","2","1",
	"EOR","a,y","4","3",
	"PHY","s","3","1",
	"TCD","i","2","1",
	"JMP","al","4","4",
	"EOR","a,x","4","3",
	"LSR","a,x","7","3",
	"EOR","al,x","5","4",

	"RTS","s","6","1",
	"ADC","(d,x)","6","2",
	"PER","s","6","3",
	"ADC","d,s","4","2",
	"STZ","d","3","2",
	"ADC","d","3","2",
	"ROR","d","5","2",
	"ADC","[d]","6","2",
	"PLA","s","4","1",
	"ADC","#","2","2",
	"ROR","A","2","1",
	"RTL","s","6","1",
	"JMP","(a)","5","3",
	"ADC","a","4","3",
	"ROR","a","6","3",
	"ADC","al","5","4",

	"BVS","r","2","2",
	"ADC","(d),y","5","2",
	"ADC","(d)","5","2",
	"ADC","(d,s),y","7","2",
	"STZ","d,x","4","2",
	"ADC","d,x","4","2",
	"ROR","d,x","6","2",
	"ADC","[d],y","6","2",
	"SEI","i","2","1",
	"ADC","a,y","4","3",
	"PLY","s","4","1",
	"TDC","i","2","1",
	"JMP","(a,x)","6","3",
	"ADC","a,x","4","3",
	"ROR","a,x","7","3",
	"ADC","al,x","5","4",

	"BRA","r","2","2",
	"STA","(d,x)","6","2",
	"BRL","rl","4","3",
	"STA","d,s","4","2",
	"STY","d","3","2",
	"STA","d","3","2",
	"STX","d","3","2",
	"STA","[d]","2","2",
	"DEY","i","2","1",
	"BIT","#","2","2",
	"TXA","i","2","1",
	"PHB","s","3","1",
	"STY","a","4","3",
	"STA","a","4","3",
	"STX","a","4","3",
	"STA","al","5","4",

	"BCC","r","2","2",
	"STA","(d),y","6","2",
	"STA","(d)","5","2",
	"STA","(d,s),y","7","2",
	"STY","d,x","4","2",
	"STA","d,x","4","2",
	"STX","d,y","4","2",
	"STA","[d],y","6","2",
	"TYA","i","2","1",
	"STA","a,y","5","3",
	"TXS","i","2","1",
	"TXY","i","2","1",
	"STZ","a","4","3",
	"STA","a,x","5","3",
	"STZ","a,x","5","3",
	"STA","al,x","5","4",
	
	"LDY","#","2","2",
	"LDA","(d,x)","6","2",
	"LDX","#","2","2",
	"LDA","d,s","4","2",
	"LDY","d","3","2",
	"LDA","d","3","2",
	"LDX","d","3","2",
	"LDA","[d]","6","2",
	"TAY","i","2","1",
	"LDA","#","2","2",
	"TAX","i","2","1",
	"PLB","s","4","1",
	"LDY","a","4","3",
	"LDA","a","4","3",
	"LDX","a","4","3",
	"LDA","al","5","4",

	"BCS","r","2","2",
	"LDA","(d),y","5","2",
	"LDA","(d)","5","2",
	"LDA","(d,s),y","7","2",
	"LDY","d,x","4","2",
	"LDA","d,x","4","2",
	"LDX","d,y","4","2",
	"LDA","[d],y","6","2",
	"CLV","i","2","1",
	"LDA","a,y","4","3",
	"TSX","i","2","1",
	"TYX","i","2","1",
	"LDY","a,x","4","3",
	"LDA","a,x","4","3",
	"LDX","a,y","4","3",
	"LDA","al,x","5","4",

	"CPY","#","2","2",
	"CMP","(d,x)","6","2",
	"REP","#","3","2",
	"CMP","d,s","4","2",
	"CPY","d","3","2",
	"CMP","d","3","2",
	"DEC","d","5","2",
	"CMP","[d]","6","2",
	"INY","i","2","1",
	"CMP","#","2","2",
	"DEX","i","2","1",
	"WAI","i","3","1",
	"CPY","a","4","3",
	"CMP","a","4","3",
	"DEC","a","6","3",
	"CMP","al","5","4",

	"BNE","r","2","2",
	"CMP","(d),y","5","2",
	"CMP","(d)","5","2",
	"CMP","(d,s),y","7","2",
	"PEI","s","6","2",
	"CMP","d,x","4","2",
	"DEC","d,x","6","2",
	"CMP","[d],y","6","2",
	"CLD","i","2","1",
	"CMP","a,y","4","3",
	"PHX","s","3","1",
	"STP","i","3","1",
	"JML","(a)","6","3",
	"CMP","a,x","4","3",
	"DEC","a,x","7","3",
	"CMP","al,x","5","4",

	"CPX","#","2","2",
	"SBC","(d,x)","6","2",
	"SEP","#","3","2",
	"SBC","d,s","4","2",
	"CPX","d","3","2",
	"SBC","d","3","2",
	"INC","d","5","2",
	"SBC","[d]","6","2",
	"INX","i","2","1",
	"SBC","#","2","2",
	"NOP","i","2","1",
	"XBA","i","3","1",
	"CPX","a","4","3",
	"SBC","a","4","3",
	"INC","a","6","3",
	"SBC","al","5","4",

	"BEQ","r","2","2",
	"SBC","(d),y","5","2",
	"SBC","(d)","5","2",
	"SBC","(d,s),y","7","2",
	"PEA","s","5","3",
	"SBC","d,x","4","2",
	"INC","d,x","6","2",
	"SBC","[d],y","6","2",
	"SED","i","2","1",
	"SBC","a,y","4","3",
	"PLX","s","4","1",
	"XCE","i","2","1",
	"JSR","(a,x)","8","3",
	"SBC","a,x","4","3",
	"INC","a,x","7","3",
	"SBC","al,x","5","4",
	
};

int read_value(FILE *input, int pass, unsigned long &value, int &count, unsigned char &mods)
{
	value = 0;
	count = 0;
	mods = 0x00;

	int bytes = 1;
	char buffer = 0;

	char name[256];

	for (int i=0; i<256; i++) name[i] = 0;

	int total = 0;

	int dist = 0;

	unsigned char changes = 0x00;
	
	bool comment = false;

	while (bytes > 0 && buffer != '\n')
	{
		bytes = fscanf(input, "%c", &buffer);
		
		if (bytes > 0 && buffer != '\n')
		{
			if (buffer >= '0' && buffer <= '9' && comment == false)
			{
				value *= 16;
				value += (unsigned long)(buffer - '0');

				count++;
			}
			else if (buffer >= 'A' && buffer <= 'F' && comment == false)
			{
				value *= 16;
				value += (unsigned long)(buffer - 'A' + 10);

				count++;
			}
			else if (((buffer >= 'a' && buffer <= 'z') || buffer == '_') && comment == false)
			{
				name[total] = buffer;
				total++;
			}
			else if (buffer == ';')
			{
				comment = true;
			}
			else if (comment == false)
			{
				if (buffer == '#')
				{
					mods = mods | 0x01;
				}
				else if (buffer == '(' || buffer == ')')
				{
					mods = mods | 0x02;
				}
				else if (buffer == '[' || buffer == ']')
				{
					mods = mods | 0x04;
				}
				else if (buffer == 'X')
				{
					mods = mods | 0x08;
				}
				else if (buffer == 'Y')
				{
					mods = mods | 0x10;
				}
				else if (buffer == 'S')
				{
					mods = mods | 0x20;
				}
				else if (buffer == '<')
				{
					changes = changes | 0x01;
				}
				else if (buffer == '>')
				{
					changes = changes | 0x02;
				}
				else if (buffer == '=')
				{
					changes = changes | 0x04;
				}
				else if (buffer == '^')
				{
					changes = changes | 0x08;
				}
				else if (buffer == '+')
				{
					dist++;
				}
				else if (buffer == '-')
				{
					dist--;
				}
			}
		}
	}

	if (total > 0)
	{
		comment = false;

		for (unsigned long i=0; i<equal_total; i++)
		{
			if (strcmp(name, equal_name[i]) == 0)
			{
				value = equal_location[i];
				count = 6;

				comment = true;
			
				break;
			}
		}

		if (comment == false)
		{
			for (unsigned long i=0; i<label_total; i++)
			{
				if (strcmp(name, label_name[i]) == 0)
				{
					value = label_location[i];
					count = 4;
	
					comment = true;
				
					break;
				}
			}

			if (comment == false) 
			{
				if (pass >= number_of_passes-1) // not on first or second passes
				{
					printf("Line %lu: Unknown equal/label %s\n", current_line, name);
				}
			}
		}
	}

	if (dist != 0)
	{
		if (dist < 0) dist++;

		comment = false;

		for (unsigned long i=0; i<star_total-1; i++)
		{
			if (star_location[i] <= current_location &&
				star_location[i+1] > current_location)
			{
				comment = true;	

				if (i+dist >= 0 && i+dist < star_total)
				{
					value = star_location[i+dist];
					count = 4;
				}
				else
				{
					if (pass >= number_of_passes-1) // not on first or second passes
					{
						printf("Line %lu: Unknown star location\n", current_line);
					}
				}

				break;
			}
		}

		if (comment == false)
		{
			if (pass >= number_of_passes-1) // not on first or second passes
			{
				printf("Line %lu: Unknown star location\n", current_line);
			}
		}
	}

	if ((changes & 0x01) > 0) // <
	{
		value = (unsigned long)(value % 256);
		count = 2;
	}
	else if ((changes & 0x02) > 0) // <
	{
		value = (unsigned long)(value / 256) % 256;
		count = 2;
	}
	else if ((changes & 0x04) > 0) // =
	{
		value = (unsigned long)(value % 65536);
		count = 4;
	}
	else if ((changes & 0x08) > 0) // ^
	{
		value = (unsigned long)(value / 65536) % 256;
		count = 2;
	}

	if (count >= 6)
	{
		value = value;
	}
	else if (count >= 4)
	{
		value = (value % 65536);
	}
	else if (count >= 2)
	{
		value = (value % 256);
	}
	else
	{
		value = 0;
	}

	return bytes;
};

int read_line(FILE *input, int pass)
{
	int bytes = 1;
	char buffer = 0;
	int count;
	int tally;
	char name[256];
	unsigned long value;
	bool comment;
	bool quotes;
	
	unsigned char mods;
	signed long dist;
	
	bool loop = true;

	while (bytes > 0 && loop == true)
	{
		bytes = fscanf(input, "%c", &buffer);

		if (bytes > 0)
		{
			if (buffer == '\n') // new line
			{
				loop = false;
			}
			else if (buffer == ';') // comment
			{
				while (bytes > 0 && buffer != '\n')
				{
					bytes = fscanf(input, "%c", &buffer);
				}

				loop = false;
			}
			else if (buffer == ':') // label
			{
				count = 0;

				comment = false;

				while (bytes > 0 && buffer != '\n')
				{
					bytes = fscanf(input, "%c", &buffer);

					if (bytes > 0 && ((buffer >= 'a' && buffer <= 'z') || buffer == '_') && comment == false)
					{
						label_name[label_count][count] = buffer;
					
						count++;
					}
					else if (bytes > 0 && buffer == ';')
					{
						comment = true;
					}
				}

				label_location[label_count] = current_location;

				label_count++;

				if (pass == 0) label_total++;
				
				loop = false;
			}
			else if (buffer == '.') // command
			{
				for (int i=0; i<256; i++) name[i] = 0;
				
				count = 0;

				comment = false;

				while (bytes > 0 && (buffer != ' ' && buffer != '\n'))
				{
					bytes = fscanf(input, "%c", &buffer);
		
					if (bytes > 0 && (buffer >= 'A' && buffer <= 'Z') && comment == false)
					{
						name[count] = buffer;

						count++;
					}
					else if (bytes > 0 && buffer == ';')
					{
						comment = true;
					}
				}

				if (strcmp(name, "EQU") == 0)
				{
					count = 0;
	
					value = 0;

					comment = false;

					while (bytes > 0 && buffer != '\n')
					{
						bytes = fscanf(input, "%c", &buffer);

						if (bytes > 0 && ((buffer >= 'a' && buffer <= 'z') || buffer == '_') && comment == false)
						{
							equal_name[equal_count][count] = buffer;
						
							count++;
						}
						else if (bytes > 0 && (buffer >= '0' && buffer <= '9') && comment == false)
						{
							value *= 16;
							value += (unsigned long)(buffer - '0');
						}
						else if (bytes > 0 && (buffer >= 'A' && buffer <= 'F') && comment == false)
						{
							value *= 16;
							value += (unsigned long)(buffer - 'A' + 10);
						}
						else if (bytes > 0 && buffer == ';')
						{
							comment = true;
						}
					}

					equal_location[equal_count] = value;
	
					equal_count++;

					if (pass == 0) equal_total++;
				}
				else if (strcmp(name, "DAT") == 0)
				{
					value = 0;

					tally = 0;

					for (int i=0; i<256; i++) name[i] = 0;
				
					count = 0;

					comment = false;

					quotes = false;

					while (bytes > 0 && buffer != '\n')
					{
						bytes = fscanf(input, "%c", &buffer);

						if (bytes > 0 && buffer != '\n' && quotes == true)
						{
							if (buffer == '"') quotes = false;
							else
							{
								binary_code[current_location] = (unsigned char)(buffer);

								current_location += 1;
							}
						}
						else
						{
							if (bytes > 0 && ((buffer >= 'a' && buffer <= 'z') || buffer == '_') && comment == false)
							{
								name[count] = buffer;
							
								count++;
							}
							else if (bytes > 0 && (buffer >= '0' && buffer <= '9') && comment == false)
							{
								value *= 16;
								value += (unsigned long)(buffer - '0');
	
								tally++;
							}
							else if (bytes > 0 && (buffer >= 'A' && buffer <= 'F') && comment == false)
							{
								value *= 16;
								value += (unsigned long)(buffer - 'A' + 10);
	
								tally++;
							}
							else if (bytes > 0 && buffer == '"' && comment == false)
							{
								quotes = true;
							}
							else if (bytes > 0 && buffer == ',' && comment == false)
							{
								if (tally > 0)
								{
									if (tally >= 6)
									{
										binary_code[current_location] = (unsigned char)(value % 256);
										binary_code[current_location+1] = (unsigned char)((value / 256) % 256);
										binary_code[current_location+2] = (unsigned char)((value / 65536) % 256);

										current_location += 3;
									}
									else if (tally >= 4)
									{
										binary_code[current_location] = (unsigned char)(value % 256);
										binary_code[current_location+1] = (unsigned char)((value / 256) % 256);

										current_location += 2;
									}
									else if (tally >= 2)
									{
										binary_code[current_location] = (unsigned char)(value % 256);

										current_location += 1;
									}
								}
								
								if (count > 0)
								{
									comment = false;

									for (unsigned long i=0; i<label_total; i++)
									{
										if (strcmp(name, label_name[i]) == 0)
										{
											binary_code[current_location] = (unsigned char)(label_location[i] % 256);
											binary_code[current_location+1] = (unsigned char)((label_location[i] / 256) % 256);

											current_location += 2;
								
											comment = true;
											
											break;
										}
									}

									if (comment == false) 
									{
										if (pass >= number_of_passes-1) // not on first or second passes
										{
											printf("Line %lu: Unknown label %s\n", current_line, name);
										}
									}

									comment = false;
								}

								value = 0;

								tally = 0;
	
								for (int i=0; i<256; i++) name[i] = 0;
					
								count = 0;
							}
							else if (bytes > 0 && buffer == ';')
							{
								comment = true;
							}
						}
					}

					if (tally > 0)
					{
						if (tally >= 6)
						{
							binary_code[current_location] = (unsigned char)(value % 256);
							binary_code[current_location+1] = (unsigned char)((value / 256) % 256);
							binary_code[current_location+2] = (unsigned char)((value / 65536) % 256);

							current_location += 3;
						}
						else if (tally >= 4)
						{
							binary_code[current_location] = (unsigned char)(value % 256);
							binary_code[current_location+1] = (unsigned char)((value / 256) % 256);

							current_location += 2;
						}
						else if (tally >= 2)
						{
							binary_code[current_location] = (unsigned char)(value % 256);

							current_location += 1;
						}
					}
					
					if (count > 0)
					{
						comment = false;

						for (unsigned long i=0; i<label_total; i++)
						{
							if (strcmp(name, label_name[i]) == 0)
							{
								binary_code[current_location] = (unsigned char)(label_location[i] % 256);
								binary_code[current_location+1] = (unsigned char)((label_location[i] / 256) % 256);

								current_location += 2;
					
								comment = true;
								
								break;
							}
						}

						if (comment == false) 
						{
							if (pass >= number_of_passes-1) // not on first or second passes
							{
								printf("Line %lu: Unknown label %s\n", current_line, name);
							}
						}
					}
				}
				else if (strcmp(name, "ORG") == 0)
				{
					value = 0;

					comment = false;

					while (bytes > 0 && buffer != '\n')
					{
						bytes = fscanf(input, "%c", &buffer);

						if (bytes > 0 && (buffer >= '0' && buffer <= '9') && comment == false)
						{
							value *= 16;
							value += (unsigned long)(buffer - '0');
						}
						else if (bytes > 0 && (buffer >= 'A' && buffer <= 'F') && comment == false)
						{
							value *= 16;
							value += (unsigned long)(buffer - 'A' + 10);
						}
						else if (bytes > 0 && buffer == ';')
						{
							comment = true;
						}
					}

					current_location = value;
				}
				else if (strcmp(name, "LOC") == 0)
				{
					count = 0;

					for (int i=0; i<256; i++) name[i] = 0;

					while (bytes > 0 && buffer != '\n')
					{
						bytes = fscanf(input, "%c", &buffer);

						if (bytes > 0 && buffer != '\n')
						{
							name[count] = buffer;

							count++;
						}
					}

					if (pass >= number_of_passes-1) // not on first or second passes
					{
						printf("Line %lu: $%06lx %s\n", current_line, current_location, name);
					}
				}
				else
				{
					printf("Line %lu: Unknown command %s\n", current_line, name);
				}

				loop = false;
			}
			else
			{
				if (buffer == '*') // star
				{
					while (bytes > 0 && buffer != '\n' && buffer != '\t')
					{
						bytes = fscanf(input, "%c", &buffer);
					}
	
					star_location[star_count] = current_location;
			
					star_count++;
	
					if (pass == 0) star_total++;
	
					loop = false;
				}
	
				if (buffer == '\t' && pass > 0) // instruction
				{
					for (int i=0; i<256; i++) name[i] = 0;
					
					count = 0;

					comment = false;

					buffer = 0;

					while (bytes > 0 && (buffer != ' ' && buffer != '\t' && buffer != ';' && buffer != '\n'))
					{
						bytes = fscanf(input, "%c", &buffer);
			
						if (bytes > 0 && buffer == '\n')
						{
							comment = true;
						}
						else if (bytes > 0 && buffer == ';')
						{
							comment = true;
						}
						else if (bytes > 0 && (buffer >= 'A' && buffer <= 'Z') && comment == false)
						{
							name[count] = buffer;

							count++;
						}
					}

					count = 0;
					value = 0;
					mods = 0;

					if (comment == false)
					{
						bytes = read_value(input, pass, value, count, mods);
					}
					else
					{
						while (bytes > 0 && buffer != '\n')
						{
							bytes = fscanf(input, "%c", &buffer);
						}
					}

					comment = false;
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
int main(const int argc, const char **argv)
{
	printf("Acolyte Assembler for the W65C816S 8/16-bit CPU\n");
	printf("Remember to enter native mode: CLC, then XCE\n");
	printf("Currently this does NOT implement REP #$30 and SEP #$30\n");
	printf("\n");

	for (unsigned long i=0; i<equal_max; i++)
	{
		for (int j=0; j<256; j++) equal_name[i][j] = 0;
		
		equal_location[i] = 0;
	}

	for (unsigned long i=0; i<label_max; i++)
	{
		for (int j=0; j<256; j++) label_name[i][j] = 0;
		
		label_location[i] = 0;
	}

	for (unsigned long i=0; i<star_max; i++)
	{	
		star_location[i] = 0;
	}

	if (argc < 6)
	{
		printf("Arguments: <input.asm> <output.bin> <output.hex> <output_start_bytes> <output_end_bytes>\n");
		
		return 0;
	}

	FILE *input;
	int bytes;

	for (int i=0; i<16; i++) // number of passes
	{
		printf("Pass %d\n", i+1);

		input = NULL;

		input = fopen(argv[1], "rt");
		if (!input)
		{
			printf("Error: Cannot open input file\n");
		
			return 0;
		}

		bytes = 1;

		current_location = 0; // starts at $000000

		current_line = 1; // starts at Line 1

		equal_count = 0;
		label_count = 0;
		star_count = 0;

		if (i == 0) // only on first pass
		{
			star_location[star_total] = 0x000000;
			star_total++;
		}

		star_count++;

		while (bytes > 0)
		{
			bytes = read_line(input, i);
		}

		if (i == 0) // only on first pass
		{
			star_location[star_total] = 0xFFFFFF;
			star_total++;
		}
	
		fclose(input);
	}

	unsigned long start_bytes = atoi(argv[4]);
	unsigned long end_bytes = atoi(argv[5]);

	if (start_bytes < 0) start_bytes = 0;
	if (end_bytes > 16777216) end_bytes = 16777216;

	FILE *output = NULL;
	
	output = fopen(argv[2], "wb");
	if (!output)
	{
		printf("Error: Cannot open binary write file\n");
	
		return 0;
	}

	for (unsigned long i=start_bytes; i<end_bytes; i++)
	{
		fprintf(output, "%c", binary_code[i]);
	}

	fclose(output);

	output = NULL;
	
	output = fopen(argv[3], "wt");
	if (!output)
	{
		printf("Error: Cannot open hex write file\n");
	
		return 0;
	}

	for (unsigned long i=start_bytes; i<end_bytes; i++)
	{
		fprintf(output, "0x%02X,", binary_code[i]);

		if (i % 16 == 15)
		{
			fprintf(output, "\n");
		}
	}

	fclose(output);

	printf("Complete\n\n");
	
/*
	// optional code below, comment out if need be
	char command[256];
	
	for (int i=0; i<256; i++) command[i] = 0;

	sprintf(command, "hexdump -C %s", argv[2]);

	system(command);
*/

	return 1;
}

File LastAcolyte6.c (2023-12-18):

// LastAcolyte6 C code for PIC16F886
// Bootloader and I/O device

/*

cd ~/Projects/PIC16 ; ~/Projects/sdcc-4.3.0/bin/sdcc --use-non-free -mpic14 -p16f886 LastAcolyte6.c ; cd ~/Projects/minipro ; ./minipro -p "pic16f886" -w ~/Projects/PIC16/LastAcolyte6.hex ; ./minipro -p "pic16f886" -c config -w ~/Projects/PIC16/LastAcolyte6.fuses -e

cd ~/Projects/PIC16 ; ~/Projects/sdcc-4.3.0/bin/sdcc --use-non-free -mpic14 -p16f887 LastAcolyte6.c ; cd ~/Projects/minipro ; ./minipro -p "pic16f887@DIP40" -w ~/Projects/PIC16/LastAcolyte6.hex ; ./minipro -p "pic16f887@DIP40" -c config -w ~/Projects/PIC16/LastAcolyte6.fuses -e

*/

/* 
The config words in sdcc don't work with the TL866II+ programmer,
so you need to make sure to have the LastAcolyte6.fuses file look like this:

word1 = 0x2cf4
word2 = 0x3eff
user_id0 = 0x3fff
user_id1 = 0x3fff
user_id2 = 0x3fff
user_id3 = 0x3fff
*/

/*
RA0-RA7 = DATA-BUS

RB0 = RDY, input, used in booting, later is active on PIC when low, used to interrupt
RB1 = PHI2-3V3, inout, controlled by PIC in boot, floating when not
RB2 = /BOOT, output, tells CPLD and transceiver to stay in bootloader mode
RB3 = /VP, input, used to sense CPU status in boot
RB4 = VPA, input, used to sense CPU status in boot
RB5 = VDA, input, used to sense CPU status in boot
RB6 = /NMI, inout, grounded on regular timed intervals, floating (pulled high) when not
RB7 = /RES, inout, grounded upon start of boot, then grounded to exit boot

RC0 = SPI-CLK, output, connects to SDcard
RC1 = SPI-MOSI, output, connects to SDcard
RC2 = SPI-CS, input, connects to SDcard
RC3 = SPI-MISO, output, connects to SDcard
RC4 = DSR, input, for possible FT232RL
RC5 = RTS, output, for possible FT232RL
RC6 = TX/CK, output, for possible FT232RL
RC7 = RX/DT, input, for possible FT232RL

RE3 = /MCLR, master clear
*/

/*
The boot sequence is as follows:
	Bring /RES low and gain control of PHI2.
	Release /RES to be pulled high, start single stepping CPU.
	When /VP goes low, send $0000 reset vector (arbitrary).
	Send LDA# and STAal instructions, filling $FE00-$FFFF with boot code.
	If SDcard is ready, send 128KB of data as well.
	When done, send WAI instruction to bring RDY low.
	Release PHI2, bring /RES low again.
	Setup PIC interrupts.
	Then release /RES to start the CPU running!
*/

/*
The SDcard command sequence is as follows:
	CPU turns off /IRQ interrupts entirely. 
	VIA puts command on PA, and enters special copy sub-routine.
	CPU uses the WAI command, bringing RDY low.
	PIC interrupts on falling edge of RDY.
	PIC reads command then toggles /NMI, bringing RDY high.
	VIA has more command data, PIC waits for RDY to fall, repeat three more times.
	VIA then make PA as input and issues WAI command.
	PIC puts "SDcard Ready" on PA and toggles /NMI.
	If SDcard was not ready, exit sub-routine, else, expect 512 bytes of data (incoming or outgoing).
	PIC waits for RDY to fall, then either sends or receives data on PA, then toggles /NMI, repeat.
	...
	CPU exits sub-routine.
	CPU turns /IRQ interrupts back on.
*/
	


// must have the library file locally in the same folder
#include "pic16f886.h"
//#include "pic16f887.h"


// these are useless here, but keeping them here for 'posterity' sake
unsigned int __at _CONFIG1 config1 = 0x2CF4;
unsigned int __at _CONFIG2 config2 = 0x3EFF;


// a short delay
void delay(void)
{
	unsigned char value = 0x00;

	while (value < 0x10) // arbitrary wait time
	{
		value = value + 1;
	}
}

// toggles PHI2 from low to high to low again
void toggle(void)
{
	// assumes PHI2 is low already
	RB1 = 1; // bring PHI2 high
	// delay needed?
	RB1 = 0; // bring PHI2 low
}

void serial_initialize(void)
{
	unsigned char value = 0x00;

	TRISC = TRISC | 0x80; // make sure RX is input
	TRISC = TRISC & 0x40; // make sure TX is output
	
	SPBRG = 25; // 4000000 / (64 * (9600 + 1)); // formula to set baud rate at 9600
	TXSTA = 0x24; // 'high speed' transmit enabled
	RCSTA = 0x90; // serial port enabled, continuous receives

	do
	{
		value = value + 1;
	}
	while (value != 0x00); // short delay
}

char serial_receivechar(void)
{
	while (RCIF == 0) { } // wait to receive character
	RCIF = 0; // clear flag

	return RCREG;
}

void serial_transmitchar(char value)
{
	while (TXIF == 0) { } // wait to transmit character
	TXIF = 0; // clear flag

	TXREG = value;
}

void serial_error(void)
{
	serial_transmitchar('E');
	serial_transmitchar('r');
	serial_transmitchar('r');
	serial_transmitchar('\n');
	serial_transmitchar('\r'); // send message to computer

	while (1) { } // loop forever
}

void rdy_wait(void)
{
	while (RB0 == 1) { } // wait for RDY to fall from WAI instruction
}

void nmi_ground(void)
{
	while (RB6 == 0) { } // wait for /NMI to be high
	RB6 = 0; // get /NMI ready for low
	TRISB = TRISB & 0xBF; // /NMI is output
}

void nmi_float(void)
{
	TRISB = TRISB | 0x60; // release /NMI, pulled high
}

// tells if the initialization process worked or not
unsigned char sdcard_ready = 0x00;

// blocks for SDcard
unsigned char sdcard_block_high = 0x00;
unsigned char sdcard_block_mid = 0x00;
unsigned char sdcard_block_low = 0x00;

// SDcard commands below
// This was used for the Arduino, but has been modified to work here.
void sdcard_enable(void)
{
	RC2 = 0; // CS is low
}

void sdcard_disable(void)
{
	RC2 = 1; // CS is high
}

void sdcard_toggle(void)
{
	RC0 = 1; // CLK is high
	// delay?
	RC0 = 0; // CLK is low
}

void sdcard_longdelay(void)
{
	unsigned int tally = 0x0000;

	while (tally < 0x0200) // arbitrary amount of time to delay, should be around 10ms
	{
		tally = tally + 1;
	}
}

void sdcard_sendbyte(unsigned char value)
{
	unsigned char temp_value = value;

	for (unsigned char i=0; i<8; i++)
	{
		if (temp_value >= 0x80)
		{
			RC1 = 1; // MOSI is high
		}
		else
		{
			RC1 = 0; // MOSI is low
		}

		temp_value = temp_value << 1;

		sdcard_toggle();
	}
}

unsigned char sdcard_receivebyte(void)
{
	unsigned char temp_value = 0x00;

	for (unsigned char i=0; i<8; i++)
	{
		temp_value = temp_value << 1;

		if (RC3) // if MISO is high...
		{
			temp_value += 0x01;
		}

		sdcard_toggle();
	}

	return temp_value;
}

unsigned char sdcard_waitresult(void)
{
	unsigned char temp_value = 0xFF;

	for (unsigned int i=0; i<2048; i++) // arbitrary wait time
	{
		temp_value = sdcard_receivebyte();

		if (temp_value != 0xFF)
		{
			return temp_value;
		}
	}

	return 0xFF;
}

void sdcard_pump(void)
{
	RC2 = 1; // CS is high, must disable the device
	RC1 = 1; // MOSI is high, AND leave mosi high!!!

	sdcard_longdelay();

	for (unsigned char i=0; i<80; i++)
	{
		sdcard_toggle();
	}
}
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

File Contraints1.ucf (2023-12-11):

NET emu LOC = P39;

NET shift_clock LOC = P40;
NET shift_data LOC = P41;

NET boot LOC = P42;

NET master_clock LOC = P43;
NET phi2 LOC = P44;
NET not_phi2 LOC = P1;

NET visible LOC = P2;
NET nmi LOC = P3;

NET ram_a LOC = P29;
NET ram_b LOC = P30;
NET via LOC = P31;

NET zero LOC = P32;

NET rw LOC = P33;
NET wr LOC = P34;
NET rd LOC = P36;

NET vsync LOC = P37;
NET hsync LOC = P38;

NET bank[0] LOC = P5;
NET bank[1] LOC = P6;
NET bank[2] LOC = P7;
NET bank[3] LOC = P8;

NET address[0] LOC = P12;
NET address[1] LOC = P13;
NET address[2] LOC = P14;
NET address[3] LOC = P16;

NET address[4] LOC = P18;
NET address[5] LOC = P19;
NET address[6] LOC = P20;
NET address[7] LOC = P21;

NET address[8] LOC = P22;

NET top[0] LOC = P23;
NET top[1] LOC = P27;
NET top[2] LOC = P28;
